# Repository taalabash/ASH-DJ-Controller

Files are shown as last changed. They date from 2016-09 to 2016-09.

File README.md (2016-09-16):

# ASH-DJ-Controller

ASH DJ controller is a basic dj controller for arduino mega 2560 , it basicly sends midi signals to the pc to control a dj software like Virtual-DJ 
this platform apears as generic midi controller in windows device manager (thanks to MOCO-LUFA)

the controller can handle :

* x40 keys with 16 of them that can change its function based on a mode key for each 8 with 5 modes for each groupe and there is a shift    key that can change the keys function in mode 5 (like the shift key for delete cue)
* x32 faders or potentiometer with 4 of them that changes its signals based on the mode switches (2 for each mode switch)
* x2 encoders
* x2 5-way mode switches (it can be used to switch between loops , hot cue , samplers , etc...)
* x2 shift keys (it can be used to delete hot cues )

there will be more featurs in future...

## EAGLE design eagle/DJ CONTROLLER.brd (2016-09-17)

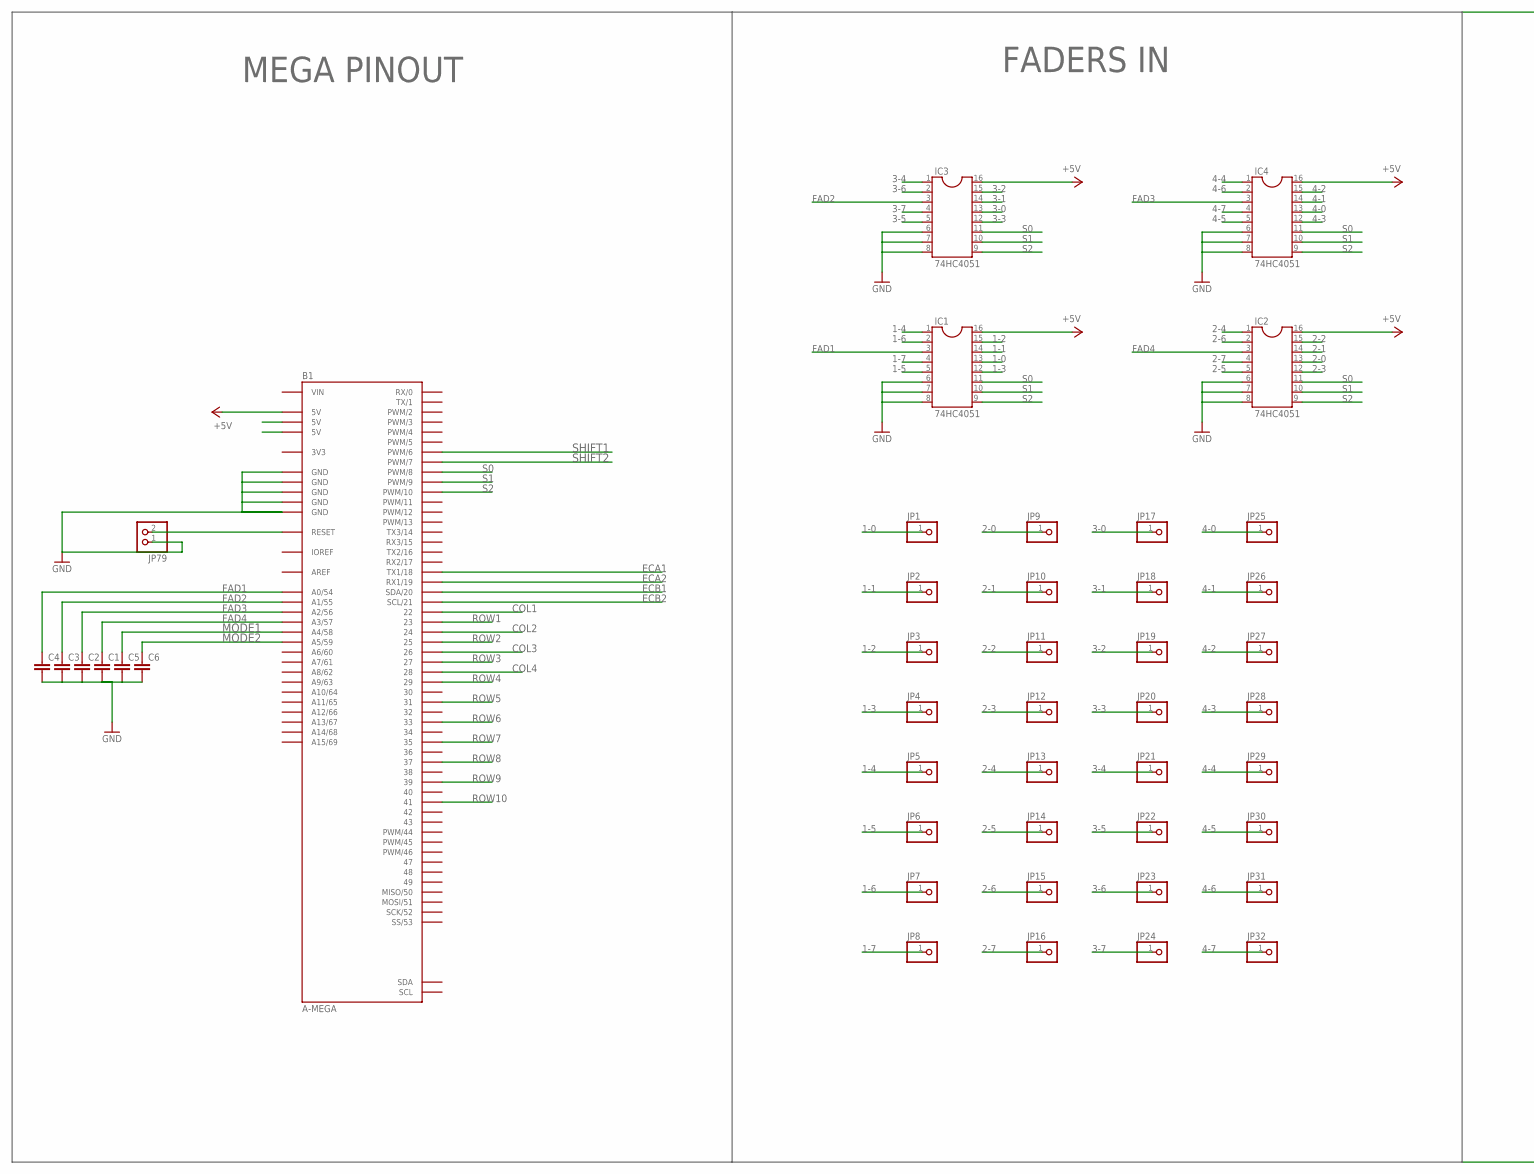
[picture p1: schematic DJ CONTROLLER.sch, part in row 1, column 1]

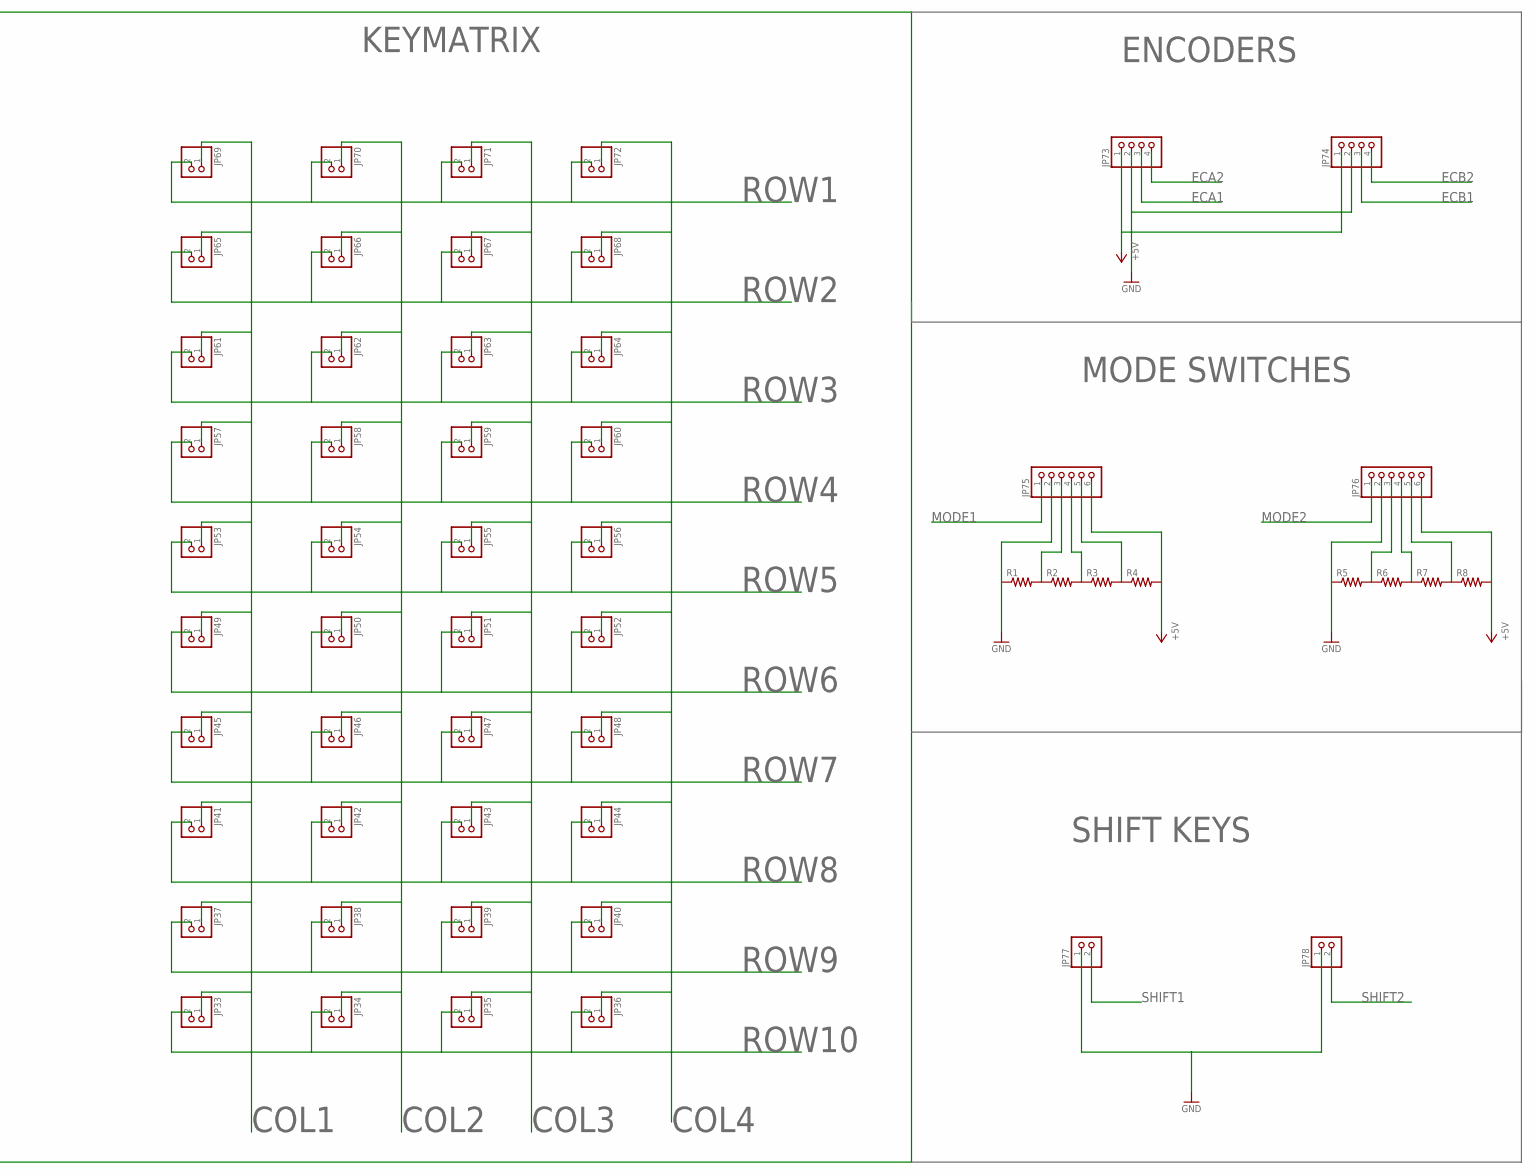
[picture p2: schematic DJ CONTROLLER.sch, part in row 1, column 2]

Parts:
B1: A-MEGA
C1, C2, C3, C4, C5, C6: C-EU050-025X075; C050-025X075
IC1, IC2, IC3, IC4: 74HC4051; SOCKET-16
JP1, JP2, JP3, JP4, JP5, JP6, JP7, JP8, JP9, JP10, JP11, JP12, JP13, JP14, JP15, JP16, JP17, JP18, JP19, JP20, JP21, JP22, JP23, JP24, JP25, JP26, JP27, JP28, JP29, JP30, JP31, JP32: PINHD-1X1; 1X01
JP33, JP34, JP35, JP36, JP37, JP38, JP39, JP40, JP41, JP42, JP43, JP44, JP45, JP46, JP47, JP48, JP49, JP50, JP51, JP52, JP53, JP54, JP55, JP56, JP57, JP58, JP59, JP60, JP61, JP62, JP63, JP64, JP65, JP66, JP67, JP68, JP69, JP70, JP71, JP72, JP77, JP78, JP79: PINHD-1X2; 1X02
JP73, JP74: PINHD-1X4; 1X04
JP75, JP76: PINHD-1X6; 1X06
R1, R2, R3, R4, R5, R6, R7, R8: R-US_0204/7; 0204/7

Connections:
1-0: IC1.13, JP1.1
1-1: IC1.14, JP2.1
1-2: IC1.15, JP3.1
1-3: IC1.12, JP4.1
1-4: IC1.1, JP5.1
1-5: IC1.5, JP6.1
1-6: IC1.2, JP7.1
1-7: IC1.4, JP8.1
2-0: IC2.13, JP9.1
2-1: IC2.14, JP10.1
2-2: IC2.15, JP11.1
2-3: IC2.12, JP12.1
2-4: IC2.1, JP13.1
2-5: IC2.5, JP14.1
2-6: IC2.2, JP15.1
2-7: IC2.4, JP16.1
3-0: IC3.13, JP17.1
3-1: IC3.14, JP18.1
3-2: IC3.15, JP19.1
3-3: IC3.12, JP20.1
3-4: IC3.1, JP21.1
3-5: IC3.5, JP22.1
3-6: IC3.2, JP23.1
3-7: IC3.4, JP24.1
3V3: B1.3V3
4-0: IC4.13, JP25.1
4-1: IC4.14, JP26.1
4-2: IC4.15, JP27.1
4-3: IC4.12, JP28.1
4-4: IC4.1, JP29.1
4-5: IC4.5, JP30.1
4-6: IC4.2, JP31.1
4-7: IC4.4, JP32.1
+5V: B1.5V@1 (5V), IC1.16, IC2.16, IC3.16, IC4.16, JP73.1, JP74.1, JP75.6, JP76.6, R4.2, R8.2
AREF: B1.AREF
COL1: B1.22, JP33.1, JP37.1, JP41.1, JP45.1, JP49.1, JP53.1, JP57.1, JP61.1, JP65.1, JP69.1
COL2: B1.24, JP34.1, JP38.1, JP42.1, JP46.1, JP50.1, JP54.1, JP58.1, JP62.1, JP66.1, JP70.1
COL3: B1.26, JP35.1, JP39.1, JP43.1, JP47.1, JP51.1, JP55.1, JP59.1, JP63.1, JP67.1, JP71.1
COL4: B1.28, JP36.1, JP40.1, JP44.1, JP48.1, JP52.1, JP56.1, JP60.1, JP64.1, JP68.1, JP72.1
ECA1: B1.18 (TX1/18), JP73.3
ECA2: B1.19 (RX1/19), JP73.4
ECB1: B1.20 (SDA/20), JP74.3
ECB2: B1.21 (SCL/21), JP74.4
FAD1: B1.A0 (A0/54), C4.1, IC1.3
FAD2: B1.A1 (A1/55), C3.1, IC3.3
FAD3: B1.A2 (A2/56), C2.1, IC4.3
FAD4: B1.A3 (A3/57), C1.1, IC2.3
GND: B1.GND@1 (GND), B1.GND@2 (GND), B1.GND@3 (GND), B1.GND@4 (GND), B1.GND@5 (GND), C1.2, C2.2, C3.2, C4.2, C5.2, C6.2, IC1.6, IC1.7, IC1.8, IC2.6, IC2.7, IC2.8, IC3.6, IC3.7, IC3.8, IC4.6, IC4.7, IC4.8, JP73.2, JP74.2, JP75.2, JP76.2, JP77.1, JP78.1, JP79.1, R1.1, R5.1
IOREF: B1.IOREF
MODE1: B1.A4 (A4/58), C5.1, JP75.1
MODE2: B1.A5 (A5/59), C6.1, JP76.1
unnamed: JP76.3, R5.2, R6.1
unnamed: JP75.3, R1.2, R2.1
unnamed: JP75.4, R2.2, R3.1
unnamed: JP75.5, R3.2, R4.1
unnamed: JP76.4, R6.2, R7.1
unnamed: JP76.5, R7.2, R8.1
unnamed: B1.RST (RESET), JP79.2
ROW1: B1.23, JP69.2, JP70.2, JP71.2, JP72.2
ROW2: B1.25, JP65.2, JP66.2, JP67.2, JP68.2
ROW3: B1.27, JP61.2, JP62.2, JP63.2, JP64.2
ROW4: B1.29, JP57.2, JP58.2, JP59.2, JP60.2
ROW5: B1.31, JP53.2, JP54.2, JP55.2, JP56.2
ROW6: B1.33, JP49.2, JP50.2, JP51.2, JP52.2
ROW7: B1.35, JP45.2, JP46.2, JP47.2, JP48.2
ROW8: B1.37, JP41.2, JP42.2, JP43.2, JP44.2
ROW9: B1.39, JP37.2, JP38.2, JP39.2, JP40.2
ROW10: B1.41, JP33.2, JP34.2, JP35.2, JP36.2
S0: B1.8 (PWM/8), IC1.11, IC2.11, IC3.11, IC4.11
S1: B1.9 (PWM/9), IC1.10, IC2.10, IC3.10, IC4.10
S2: B1.10 (PWM/10), IC1.9, IC2.9, IC3.9, IC4.9
SHIFT1: B1.6 (PWM/6), JP77.2
SHIFT2: B1.7 (PWM/7), JP78.2
VIN: B1.VIN

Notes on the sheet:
FADERS IN
KEYMATRIX
ENCODERS
MEGA PINOUT
MODE SWITCHES
SHIFT KEYS

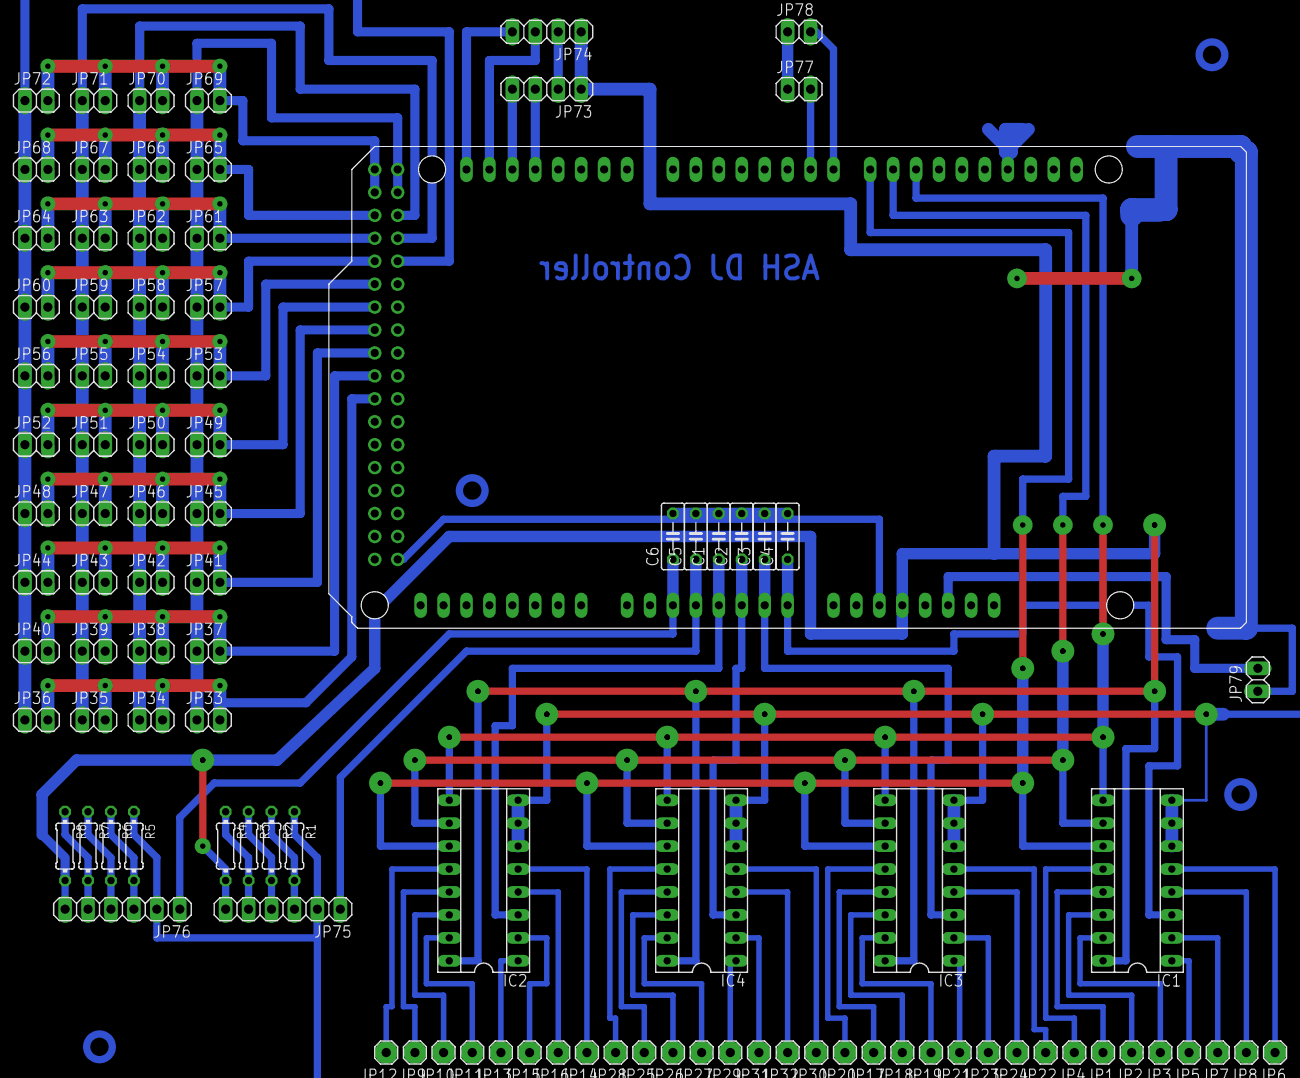
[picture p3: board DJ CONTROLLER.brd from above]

Board: 2 copper layers, 98 parts (1 on the bottom side), 70 nets.

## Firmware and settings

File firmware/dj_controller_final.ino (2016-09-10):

/* Dj controller
 *  
 *  for arduino mega 2560
 *  
 *  created 2015
 *  
 *  designed and writen by ASH
 *  
 *  taalabash@gmail.com
 *  
 *  this frimware can hanle number of buttons that can be changed by a mode key
 *  2 shift buttons to change hot cue mode for each deck
 *   
 */

#define ENCODER_OPTIMIZE_INTERRUPTS
#include <Encoder.h>
#include <MIDI.h>
MIDI_CREATE_DEFAULT_INSTANCE();

//_____________// MIDI ////__________________________________________________________________________________________________________

//0, 1, 2, 3, 4, are token for mode keys don't use them ... !!!! hot cues , loops , slicer , rolls , samplers
//5 for mode shift keys  and shift keys are only for hot cues (on mode4 ) so we can call them "delete hot cue" and the msgs while pressing shift key will be sent to channel 5
//                         ___
//6 for keys                  |
//7 for faders                |
//8 for encoders              |--->  as defined below  ||
//9 listen channel         ___|                        \/

#define MIDI_BUTTON_CHANNEL  6
#define MIDI_FADER_CHANNEL   7   //fader on the last multiplexer will send to the mode channel...
#define MIDI_ENCODER_CHANNEL 8
#define MIDI_LISTEN_CHANNEL  9 



//_____________// FADER & POTIS ////__________________________________________________________________________________________________

#define NR_OF_MULTIPLEXERS 4
const int pinmultiplexer[NR_OF_MULTIPLEXERS] = { A0,A1,A2,A3 }; //faders on the last multiplexer (on A3 here) will be sent to the mode channel
                                                                //input 4 and 5 in the last multiplexer will send its values to modechannel 1
                                                                //input 6 and 7 in the last multiplexer will send its values to modechannel 2
int faderState[NR_OF_MULTIPLEXERS][8] = {
  {0,0,0,0,0,0,0,0},
  {0,0,0,0,0,0,0,0},
  {0,0,0,0,0,0,0,0},
  {0,0,0,0,0,0,0,0}
} ;

int s0 = 8 ;
int s1 = 9 ; 
int s2 = 10 ;
                                  
int r0 ;
int r1 ;
int r2 ;

#define FADER_CHANGE_MIN 8



//_____________// BUTTONS ////________________________________________________________________________________________________________

#define KEYMATRIX_ROWS 10
#define KEYMATRIX_COLS 4         // must stay 4 because all keys are arranged based on 4 rows arrangements 
#define KEYMATRIX_DEBOUNCE 10

//row 0 ,1 for mode 1 buttons.
//row 2 ,3 for mode 2 buttons.
//other pins are for other buttons.

byte keymatrixRowPins[KEYMATRIX_ROWS] = {23 ,25 ,27 ,29 ,31 , 33, 35, 37, 39, 41}; 
byte keymatrixColPins[KEYMATRIX_COLS] = {22 , 24 , 26 , 28};

boolean keymatrixStates[KEYMATRIX_ROWS][KEYMATRIX_COLS];
unsigned long keymatrixDebounce[KEYMATRIX_ROWS][KEYMATRIX_COLS];


byte mode1pin = A4 ;  //this pin must be an analog input. because we are using less digital pins by using an analog pin with multiple resistors and switches
byte mode2pin = A5 ;  //this pin must be an analog input. 

int shift1pin = 6;
int shift2pin = 7;


//_______________// ENCODER //_____________________________________________________________


#define ENCODER_L_PIN_A 18
#define ENCODER_L_PIN_B 19

#define ENCODER_R_PIN_A 20
#define ENCODER_R_PIN_B 21




volatile byte encoderLPos = 0;
volatile byte encoderRPos = 0;

//volatile unsigned long encoderLtstamp = 0;
//volatile unsigned long encoderRtstamp = 0;

Encoder leftEncoder(ENCODER_L_PIN_A, ENCODER_L_PIN_B);
Encoder rightEncoder(ENCODER_R_PIN_A, ENCODER_R_PIN_B);

//_________________________________________________________________________________________________________________________________________________________________________________________
//_________________________________________________________________________________________________________________________________________________________________________________________



void setup() {

  
 
  Serial.begin(31250);

  
          initKeymatrix() ;
          initmodekeys() ;
          initfaders() ;
          initshiftkeys();
}





void loop() {
     checkEncoders();
     readKeymatrix() ;
     checkFaders() ;
     checkEncoders();

}






//_________________________________________________________________________________________________________________________________________________________________________________________
//_________________________________________________________________________________________________________________________________________________________________________________________
void initKeymatrix() {
  
  // clear arrays
  for (byte r=0; r<KEYMATRIX_ROWS; r++) {
    for (byte c=0; c<KEYMATRIX_COLS; c++) {
      keymatrixStates[r][c]=0;
      keymatrixDebounce[r][c]=0;
    }
  }
  
  //configure column pin modes and states
  for (byte c=0; c<KEYMATRIX_COLS; c++) {
      pinMode(keymatrixColPins[c],OUTPUT);
      digitalWrite(keymatrixColPins[c],LOW);
  }
  
  //configure row pin modes and states
  for (byte r=0; r<KEYMATRIX_ROWS; r++) {
      pinMode(keymatrixRowPins[r],INPUT);
      digitalWrite(keymatrixRowPins[r],HIGH);  // Enable the internal 20K pullup resistors for each row pin.
  }
  
}


//__________________________________________________________________________________________________

void readKeymatrix() {

  // run through cols
  for( int c=0; c<KEYMATRIX_COLS; c++) {
    digitalWrite(keymatrixColPins[c], LOW);
    
    // check rows
    for( int r=0; r<KEYMATRIX_ROWS; r++) {
      boolean currentValue = (digitalRead(keymatrixRowPins[r])<1);
      if (currentValue != keymatrixStates[r][c]) {

        // debounce
        unsigned long currentTime = millis();
        if(currentTime-KEYMATRIX_DEBOUNCE > keymatrixDebounce[r][c]) {
          
          int keyNr = r*KEYMATRIX_COLS+c;
         
          if(r==0 || r==1 )
            {sendmode1KeyMessage(keyNr, currentValue);}
          else if(r==2 || r==3)
            {sendmode2KeyMessage(keyNr, currentValue);}
          else
            {sendKeyMessage(keyNr, currentValue);}
            
          keymatrixStates[r][c] = currentValue;
          keymatrixDebounce[r][c] = currentTime;
        }
      }
    }

    // reset col
    digitalWrite(keymatrixColPins[c], HIGH);
  }

}


//____________________________________________________________________________________________________________________


void sendKeyMessage(int keyNr, boolean value) {
  if (value) {
    MIDI.sendNoteOn(byte(keyNr), 1, MIDI_BUTTON_CHANNEL);
  } else {
    MIDI.sendNoteOff(byte(keyNr), 1, MIDI_BUTTON_CHANNEL);
  }
}

void sendmode1KeyMessage(int keyNr, boolean value) {
  if (value) {
    MIDI.sendNoteOn(byte(keyNr), 1, mode1channel());
  } else {
    MIDI.sendNoteOff(byte(keyNr), 1, mode1channel());
  }
}

void sendmode2KeyMessage(int keyNr, boolean value) {
  if (value) {
    MIDI.sendNoteOn(byte(keyNr), 1, mode2channel());
  } else {
    MIDI.sendNoteOff(byte(keyNr), 1, mode2channel());
  }
}




//_________________________________________________________________________________________________________________________________________________________________________________________
//_________________________________________________________________________________________________________________________________________________________________________________________
void initshiftkeys(){
   pinMode(shift1pin ,INPUT_PULLUP);
   pinMode(shift2pin ,INPUT_PULLUP);
   }


//_________________________________________________________________________________________________________________________________________________________________________________________
//_________________________________________________________________________________________________________________________________________________________________________________________
void initmodekeys(){
  pinMode(mode1pin,INPUT);
  pinMode(mode2pin,INPUT);
}

//_________________________________________________________________________________________________________

int mode1channel(){
  int c ;
  int val = analogRead(mode1pin);
  int m = map(val , 0 , 1023 , 0 , 4 );  //we have 5 modes from 0 to 4
  
  if(m == 4 && digitalRead(shift1pin)== LOW) //if we are in mode 4 and shift key is pressed send msgs to channel 5
  {c=5;}
  else{c = m;}
  return c ;
}

int mode2channel(){
  int c ;
  int val = analogRead(mode2pin);
  int m = map(val , 0 , 1023 , 0 , 4 );  //we have 5 modes from 0 to 4
 
  if(m == 4 && digitalRead(shift2pin)== LOW) //if we are in mode 4 and shift key is pressed send msgs to channel 5
  {c=5;}
  else{c = m;}
  return c ;
}
//_________________________________________________________________________________________________________________________________________________________________________________________
//_________________________________________________________________________________________________________________________________________________________________________________________

void checkFaders() {
  for( int j=0; j<NR_OF_MULTIPLEXERS; j++ ) // for each multiplexer
  { for (int i=0; i<8; i++) {   //do the multiplexer loop (taken from arduino.cc site)
       r0 = bitRead(i,0);       
       r1 = bitRead(i,1);       
       r2 = bitRead(i,2);       
       
       digitalWrite(s0, r0);
       digitalWrite(s1, r1);
       digitalWrite(s2, r2);

          int fdrValue = analogRead(pinmultiplexer[j]); //then read the value on the current multiplexer pin
          
          if( fdrValue != faderState[j][i] ) {                                      // and decide what channel you need to send the value to .
            if( abs(fdrValue - faderState[j][i]) > FADER_CHANGE_MIN) {
              
               if(j==(NR_OF_MULTIPLEXERS-1) && i>3 && i<=5){ //input 4 and 5 in the last multiplexer will send its values to modechannel 1
                 byte note = ((j*8)+i+20);
                 MIDI.sendControlChange(note, byte(fdrValue/8), mode1channel()); // value bis 127
                 faderState[j][i] = fdrValue;}
              
               else if(j==(NR_OF_MULTIPLEXERS-1) && i>5 && i<=7){  //input 6 and 7 in the last multiplexer will send its values to modechannel 2
                 byte note = ((j*8)+i+20);
                 MIDI.sendControlChange(note, byte(fdrValue/8), mode2channel()); // value bis 127
                 faderState[j][i] = fdrValue;}
                             
               else {byte note = ((j*8)+i);
                 MIDI.sendControlChange(note, byte(fdrValue/8), MIDI_FADER_CHANNEL); // value bis 127
                 faderState[j][i] = fdrValue;}
                      }  }  }  }  }
                    

    
//____________________________________________________________________________________

void initfaders()
{ pinMode(s0, OUTPUT);    // s0
  pinMode(s1, OUTPUT);    // s1
  pinMode(s2, OUTPUT);    // s2

}


//________________________________________________________________________________________


void checkEncoders() {
  byte newPos = leftEncoder.read();
  if (newPos != encoderLPos) {
    if (newPos > encoderLPos){
    MIDI.sendControlChange(1, byte( newPos % 128 ), MIDI_ENCODER_CHANNEL); 
    encoderLPos = newPos;}
    if (newPos < encoderLPos){
    MIDI.sendControlChange(2, byte( newPos % 128 ), MIDI_ENCODER_CHANNEL); 
    encoderLPos = newPos;}
  }
  newPos = rightEncoder.read();
  if (newPos != encoderRPos) {
    if (newPos > encoderRPos){
    MIDI.sendControlChange(3, byte(newPos % 128 ), MIDI_ENCODER_CHANNEL);
    encoderRPos = newPos;}
    if (newPos < encoderRPos){
    MIDI.sendControlChange(4, byte( newPos % 128 ), MIDI_ENCODER_CHANNEL); 
    encoderRPos = newPos;}
  }
}
//________________________________________________________________________________________

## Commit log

2016-09-10 Rename DJ CONTROLLER.brd to eagle/DJ CONTROLLER.brd
    [DJ CONTROLLER.brd]
2016-09-10 Rename DJ CONTROLLER.sch to eagle/DJ CONTROLLER.sch
    [DJ CONTROLLER.sch]
2016-09-17 added noise reduction capacitors for analog inputs
    [DJ CONTROLLER.brd, DJ CONTROLLER.sch]
